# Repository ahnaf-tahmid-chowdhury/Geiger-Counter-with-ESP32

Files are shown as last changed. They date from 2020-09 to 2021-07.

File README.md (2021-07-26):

# SmartGeiger

>Development of background radiation monitoring with IoT based device

## Objectives

- Flash ESP32 with Micropython
- Setup 400v voltage output to count radioactivity from SBM-20 with 4.5M MΩ series resistor
- Measures radioactive gamma and beta and alpha radiation with quite good resolution
- Use of shields to detect particles
- Use of ULTRASONIC SENSOR to detect location of the sample
- Collcet the data from the serial and then add them to a list of array by using python script
- Use of MQTTClient to pass the observed data to network
- Use of Node-RED to programe for wiring together hardware devices, APIs and online services in new and interesting ways.

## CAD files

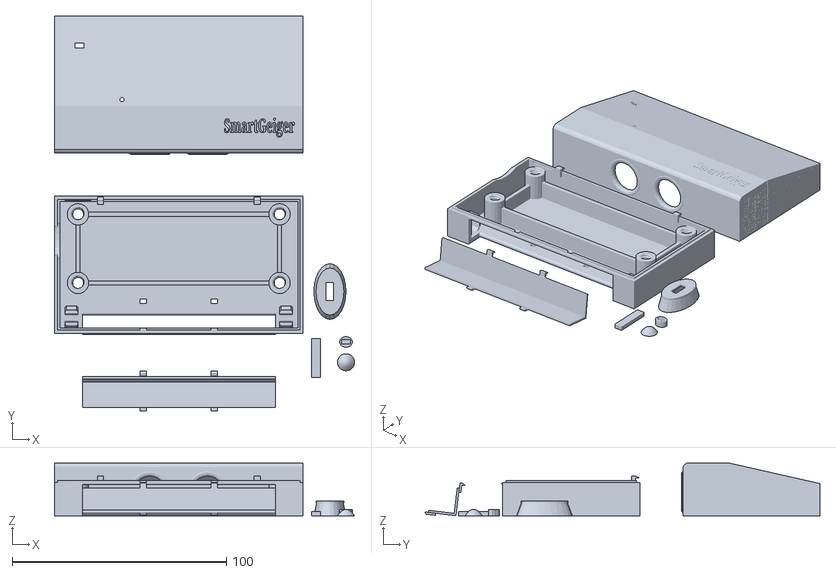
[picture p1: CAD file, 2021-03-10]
3D/SmartGeiger no support.stl
140.0 x 184.2 x 24.5

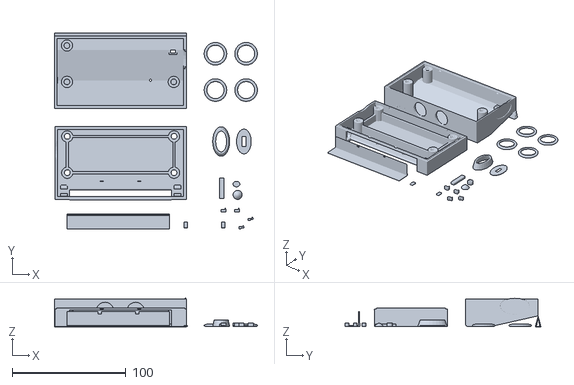
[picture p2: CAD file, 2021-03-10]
3D/SmartGeiger.stl
178.7 x 172.5 x 25.1

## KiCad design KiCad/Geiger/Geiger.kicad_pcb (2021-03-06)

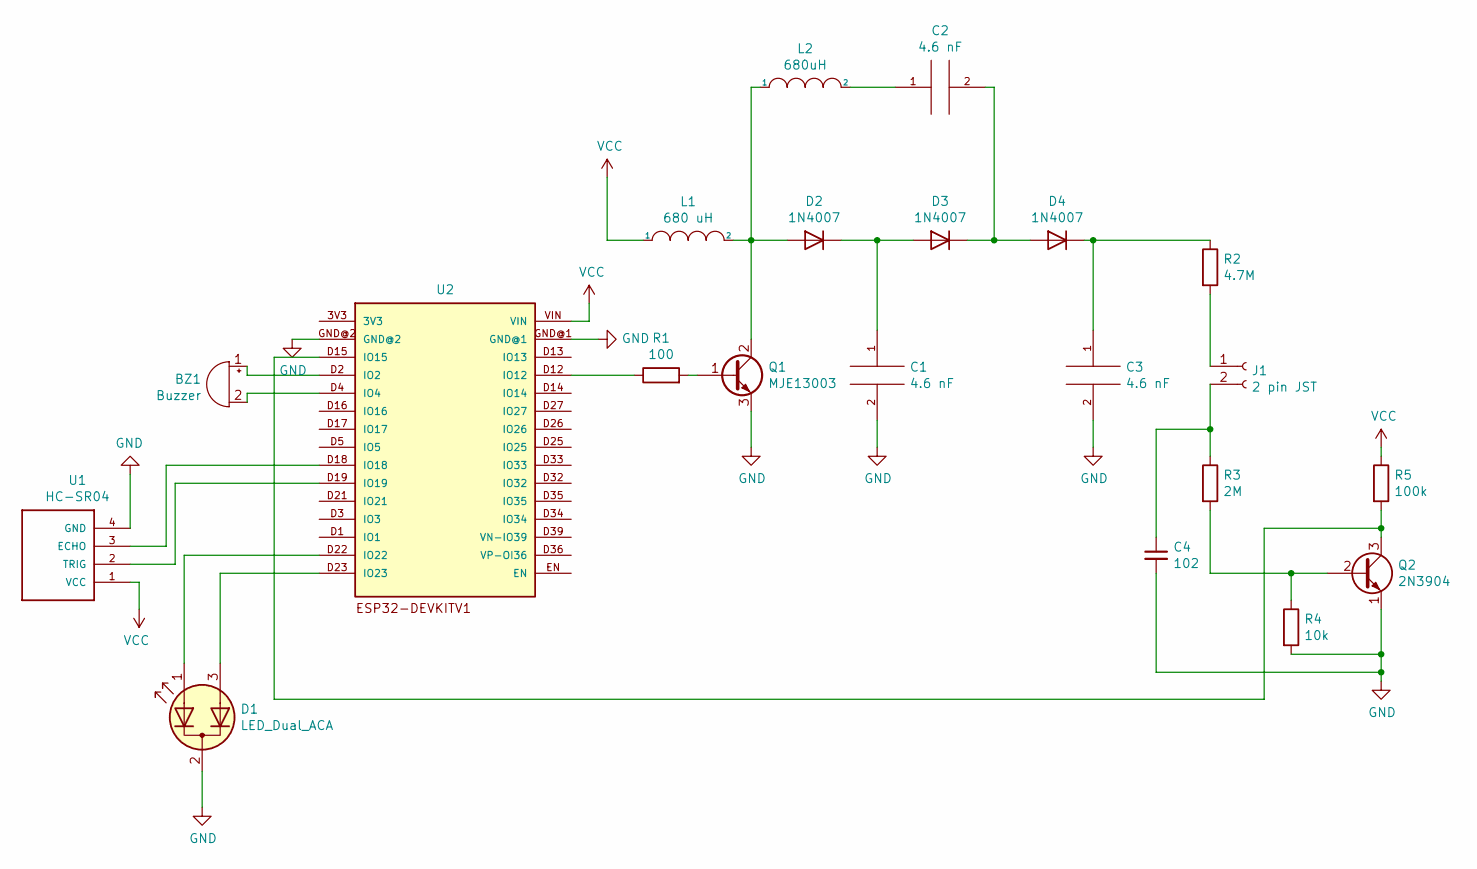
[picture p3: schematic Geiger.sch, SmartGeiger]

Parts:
BZ1: Buzzer; Buzzer_12x9.5RM7.6
C1, C2, C3: 4.6 nF; C_Rect_L13.0mm_W4.0mm_P10.00mm_FKS3_FKP3_MKS4
C4: 102; C_Disc_D3.4mm_W2.1mm_P2.50mm
D1: LED_Dual_ACA; LED_D5.0mm-3
D2, D3, D4: 1N4007; D_DO-41_SOD81_P10.16mm_Horizontal
J1: 2 pin JST; JST_EH_B2B-EH-A_1x02_P2.50mm_Vertical
L1: 680 uH; L_Axial_L9.5mm_D4.0mm_P15.24mm_Horizontal_Fastron_SMCC
L2: 680uH; L_Axial_L9.5mm_D4.0mm_P15.24mm_Horizontal_Fastron_SMCC
Q1: MJE13003; TO-126-3_Vertical
Q2: 2N3904; TO-92_Inline
R1: 100; R_Axial_DIN0207_L6.3mm_D2.5mm_P10.16mm_Horizontal
R2: 4.7M; R_Axial_DIN0207_L6.3mm_D2.5mm_P10.16mm_Horizontal
R3: 2M; R_Axial_DIN0207_L6.3mm_D2.5mm_P10.16mm_Horizontal
R4: 10k; R_Axial_DIN0207_L6.3mm_D2.5mm_P10.16mm_Horizontal
R5: 100k; R_Axial_DIN0207_L6.3mm_D2.5mm_P10.16mm_Horizontal
U1: HC-SR04; XCVR_HC-SR04
U2: ESP32DEVKITV1; ESP32-DEVKITV1

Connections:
GND: C1.2, C3.2, C4.2, D1.2 (K), Q1.3 (E), Q2.1 (E), R4.2, U1.4 (GND), U2.GND@1, U2.GND@2
unnamed: BZ1.1 (-), U2.D2 (IO2)
unnamed: BZ1.2 (+), U2.D4 (IO4)
unnamed: C1.1, D2.1 (K), D3.2 (A)
unnamed: C2.1, L2.2
unnamed: C2.2, D3.1 (K), D4.2 (A)
unnamed: C3.1, D4.1 (K), R2.1
unnamed: C4.1, J1.2, R3.1
unnamed: D1.1 (A1), U2.D22 (IO22)
unnamed: D1.3 (A2), U2.D23 (IO23)
unnamed: D2.2 (A), L1.2, L2.1, Q1.2 (C)
unnamed: J1.1, R2.2
unnamed: Q1.1 (B), R1.2
unnamed: Q2.2 (B), R3.2, R4.1
unnamed: Q2.3 (C), R5.2, U2.D15 (IO15)
unnamed: R1.1, U2.D12 (IO12)
unnamed: U1.2 (TRIG), U2.D19 (IO19)
unnamed: U1.3 (ECHO), U2.D18 (IO18)
VCC: L1.1, R5.1, U1.1 (VCC), U2.VIN

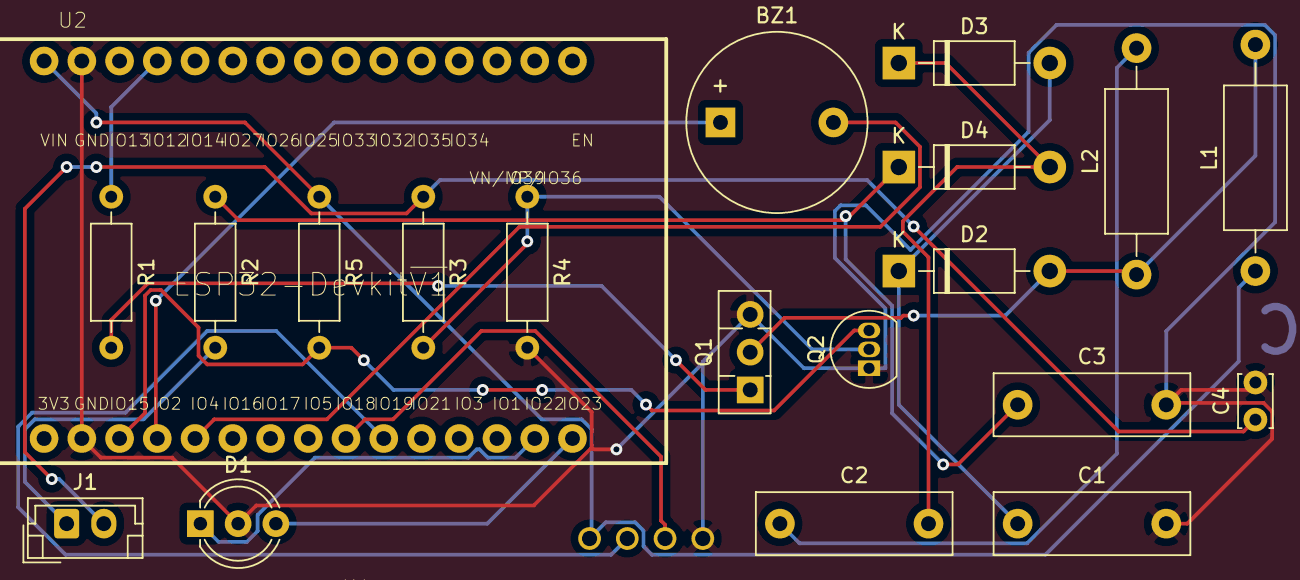
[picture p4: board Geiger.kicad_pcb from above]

Board: 2 copper layers, 21 parts (0 on the bottom side), 19 nets.

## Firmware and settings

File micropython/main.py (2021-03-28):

import esp32
from machine import freq
from utime import *
from geiger import GMtube,Buzzer,BiColorLED
from umqtt.robust import MQTTClient
import urequests
from json import loads, dumps
from hcsr04 import HCSR04
import uasyncio
import network
import webrepl

led=BiColorLED(red=22,green=23,rduty=0,gduty=1023)
f = open('config.json', 'r')
config = loads(f.read())
f.close()


def do_connect():
    wlan = network.WLAN(network.STA_IF)
    led.color(r=700,g=1023)
    wlan.active(True)
    print('connecting to network...')
    wlan.connect(config['essid'], config['password'])
    sleep(4) # wait 5 sec to connect
    if not wlan.isconnected():
        wlan.active(False)
        ap = network.WLAN(network.AP_IF)
        ap.active(True)
        ap.config(essid = config["clientID"],password = config["clientID"]) # set the ESSID of the access point with password
        while not ap.active():
            webrepl.start()
            led.color(r=400,g=700)
            pass
    led.color(r=0,g=1023)
    print('network config:', wlan.ifconfig())
mqtt_local = MQTTClient(config["clientID"], config["local_server"], port=1883)
mqtt_cloud = MQTTClient(config["clientID"], config["ubidots"],port= 1883, user = config["ubidots_key"], password = "None")

do_connect()

try:
    mqtt_local.connect()
    print("mqtt local success")
except:
    print("mqtt local faild")
    led.color(r=1023,g=0)
try:
    mqtt_cloud.connect()
    print("mqtt cloud success")
except:
    print("mqtt cloud faild")
    led.color(r=1023,g=100)

g=GMtube(12,100000,675,15)
usonic=HCSR04(trigger_pin=19,echo_pin=18)

last_tick = ticks_ms()
current_tick = ticks_ms()
CPM = []
event = 0
delta_t= 0
d2= 0
auto = 160000000


def onMessage_cloud(topic, msg):
    m=loads(msg)
    print(m["value"])
    if m["value"] == 1.0:
        config["buzzer"] = "true"
    elif m["value"] == 0.0:
        config["buzzer"] = "false"


def onMessage_local(topic, msg):
    m=loads(msg)
    print(m)
    config["config_sync"] = m["config_sync"]
    config["time_interval"] = m["time_interval"]*60
    config["local"] = m["local"]
    config["cloud"] = m["cloud"]
    config["buzzer"] = m["buzzer"]
    config["msg_alert"] = m["msg_alert"]
    config["powersave"] = m["powersave"]
    config["auto_freq"] = m["auto_freq"]
    config["max_freq"] = m["max_freq"]
    

mqtt_local.set_callback(onMessage_local)
mqtt_cloud.set_callback(onMessage_cloud)

try:
    mqtt_local.subscribe("smartgiger",qos=0)
    print("waiting for msg...")
    led.color(500, 700)
    mqtt_local.check_msg()
    
except:
    print("local subscribe faild")
    led.color(r=1023,g=0)
timer = ticks_ms()


async def geiger_count():
    global event, last_tick, current_tick, CPM, delta_t, d1
    while True:
        # check if a new event happened
        if g.count > event:

            led.color(1023, 0) if d2>200 else led.color(1023, 200) if d2>100 else led.color(1023,1023) if d2>70 else led.color(500, 950) if d2>40 else led.color(200, 1023) if d2>25 else led.color(0, 1023)
            
            event = g.count
            current_tick = ticks_ms()
            delta_t = ticks_diff(current_tick, last_tick)
            last_tick = current_tick

            if delta_t < 120000:
                CPM.append(delta_t)
                while sum(CPM) > 60000:
                    CPM.pop(0)
            
            Buzzer().buzzer() if config["buzzer"] == "true" else Buzzer().off()
            led.off()

            await uasyncio.sleep(0.00019) #dead time of GM tube


async def machine_freq():
    global freq, d2, t
    while True:
        led.color(400, 500)
        t=ticks_ms()
        if config["powersave"] == "true":
            freq(80000000)
        if config["auto_freq"] == "true":
            freq(auto)
        if config["max_freq"] == "true":
            freq(240000000)
        d2=int(d2+(d2*(ticks_ms()-t)/60000))
        led.off()
        await uasyncio.sleep_ms(500)


async def data_pass():
    global d2, d3, d4, d5, d6,d7, auto, t
    while True:
        t=ticks_us()
        d2= int(len(CPM)/2)
        d3 = d2*0.0057
        time = ticks_diff(ticks_ms(),timer)/1000
        avg = event/time
        std = (event**0.5)/time
        d4 = str(avg)+ " +/- " +str(std)
        d5 = delta_t
        d6 = usonic.distance_cm()
        d7 = (esp32.raw_temperature()-32)*5/9
        
        if config["local"] == "true":
            
            try:
                mqtt_local.publish(b"time",str(time))
                mqtt_local.publish(b"total-counts",str(event))
                mqtt_local.publish(b"cpm",str(d2))
                mqtt_local.publish(b"usv",str(d3))
                mqtt_local.publish(b"counting-rate",d4)
                mqtt_local.publish(b"delta-t",str(d5))
                mqtt_local.publish(b"distance",str(d6))
                mqtt_local.publish(b"temperature",str(d7))
                mqtt_local.publish(b"freq",str(int(freq()/1000000)))
            except:
                print("local publish failed")
                
        if d2 < 400:
            await uasyncio.sleep_ms(200)
        elif d2 < 700:
            auto = 160000000
            await uasyncio.sleep_ms(500)
        elif d2 < 1500:
            auto = 240000000
            await uasyncio.sleep_ms(800)
        elif d2 < 2500:
            await uasyncio.sleep_ms(1000)
        else:
            await uasyncio.sleep_ms(2000)



async def cloud_publish():
    global d2, t
    while True:
        if config["cloud"] == "true" :
            t=ticks_ms()

            try:
                led.color(700, 700)
                mqtt_cloud.publish("/v1.6/devices/smartgeiger/total-counts", dumps(event), qos=0,retain=False)
                mqtt_cloud.publish("/v1.6/devices/smartgeiger/cpm", dumps(d2), qos=0,retain=False)
                #added usv as a mathematical formula at ubidots
                #mqtt_cloud.publish("/v1.6/devices/smartgeiger/usv", dumps(d3), qos=0,retain=False) 
                mqtt_cloud.publish("/v1.6/devices/smartgeiger/delta-t",dumps(d5), qos=0,retain=False)
                mqtt_cloud.publish("/v1.6/devices/smartgeiger/temperature",dumps(d7), qos=0,retain=False)
                led.off()
            except:
                print("cloud publish faild")
            d2=int(d2+(d2*(ticks_ms()-t)/60000))
            
        await uasyncio.sleep(config["time_interval"])
        

async def local_subscribe():
    global config, d2, t
    while True:
        if config["config_sync"] == "true" and config["local"] == "true":
            t=ticks_ms()
            try:
                led.color(700, 700)
                mqtt_local.check_msg()
                led.off()
            except:
                print("local subscribe faild")             
            f = open('config.json', 'w')
            f.write(dumps(config))
            f.close()
            d2=int(d2+(d2*(ticks_ms()-t)/60000))
        await uasyncio.sleep(config["time_interval"])
        

async def cloud_subscribe():
    global d2, t
    global config
    while True:
        if config["cloud"] == "true":
            t=ticks_ms()
            try:
                led.color(700, 700)
                mqtt_cloud.subscribe("/v1.6/devices/smartgeiger/buzzer")
                mqtt_cloud.check_msg()
                led.off()
            except:
                print("cloud subscribe faild")
            d2=int(d2+(d2*(ticks_ms()-t)/60000))
        await uasyncio.sleep(config["time_interval"])


async def ifttt():

    while True:
        global d2, t
        if d2 > 100 and config["msg_alert"] == "true":
            t=ticks_ms()
            try:
                led.color(700, 700)
                readings = {'value1':d1, 'value2':d2, 'value3':d3}
                print(readings)
            
                request_headers = {'Content-Type': 'application/json'}

                request = urequests.post(
                    'http://maker.ifttt.com/trigger/SmartGeiger/with/key/' + config["ifttt_key"],
                    json=readings,
                    headers=request_headers)
                request.close()
                led.off()
                await uasyncio.sleep(180)
            except OSError as e:
                print('Failed to read/publish readings.')
                await uasyncio.sleep(10)
            d2=int(d2+(d2*(ticks_ms()-t)/60000))
        elif d2>200:
            await uasyncio.sleep(120)
        else:
            await uasyncio.sleep(10)

event_loop = uasyncio.get_event_loop()
event_loop.create_task(geiger_count())
event_loop.create_task(data_pass())
event_loop.create_task(machine_freq())
event_loop.create_task(cloud_publish())
event_loop.create_task(local_subscribe())
event_loop.create_task(cloud_subscribe())
event_loop.create_task(ifttt())
event_loop.run_forever()

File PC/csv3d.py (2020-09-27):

import csv
import time
import serial

data= serial.Serial("/dev/ttyUSB0",115200)
filename='PC/data3D.csv'
header1='x'
header2='y'
header3='z'

fildnames = [header1,header2,header3]
x = 0.0
y = 0.0
z = 0.0

with open(filename,"w") as csv_file:
    csv_writer = csv.DictWriter(csv_file, fieldnames = fildnames)
    csv_writer.writeheader()

while 1:
    while not data.inWaiting():
        pass
    data_read=data.readline().decode('utf-8')  # data are in byte code. decode to unicode
    data_array=data_read.split(",")

    with open(filename, 'a') as csv_file:
        csv_writer = csv.DictWriter(csv_file, fieldnames = fildnames)

        info = {
            header1 : x,
            header2 : y,
            header3 : z,
        }

        x = data_array[0]
        y = data_array[1]
        z = data_array[2]
        csv_writer.writerow(info)
        print(x,y,z)

    time.sleep(0.004)

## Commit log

2020-09-22 files updated. buzzer,geiger,main.py added
    [main.py]
2020-09-27 time added to print
2020-09-27 this is csv which is created by running csv3d
    [data3D.csv]
2020-10-29 esp debug turned off
    [data3D.csv]
2020-10-29 collected from https://github.com/HowManyOliversAreThere/hx711_mpy-driver.git
2020-10-29 removed Buzzer and Geiger and geiger added
    [main.py]
2021-03-04 ftp and ultrasonic sensor added
2021-03-04 set buzzer sleep time to 10 us
    [geiger.py]
2021-03-06 PCB for SmartGeiger created
2021-03-10 3d obj added
    [SmartGeiger no support.stl, SmartGeiger.stl]
2021-03-18 remove machine PWM

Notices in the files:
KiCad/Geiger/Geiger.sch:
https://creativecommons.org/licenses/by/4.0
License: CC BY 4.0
